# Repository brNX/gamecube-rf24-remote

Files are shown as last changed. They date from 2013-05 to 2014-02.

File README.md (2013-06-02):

# gamecube-rf24-remote

Remote control using an atmega88, nrf24l01+ and a Gamecube gamepad 

gamecube gamepad code adapted from [http://denki.world3.net/retro_v2.html](http://denki.world3.net/retro_v2.html)   
nrf24l01+ code adapted from  Maniacbug's rf24 library for arduino [https://github.com/maniacbug/RF24](https://github.com/maniacbug/RF24)

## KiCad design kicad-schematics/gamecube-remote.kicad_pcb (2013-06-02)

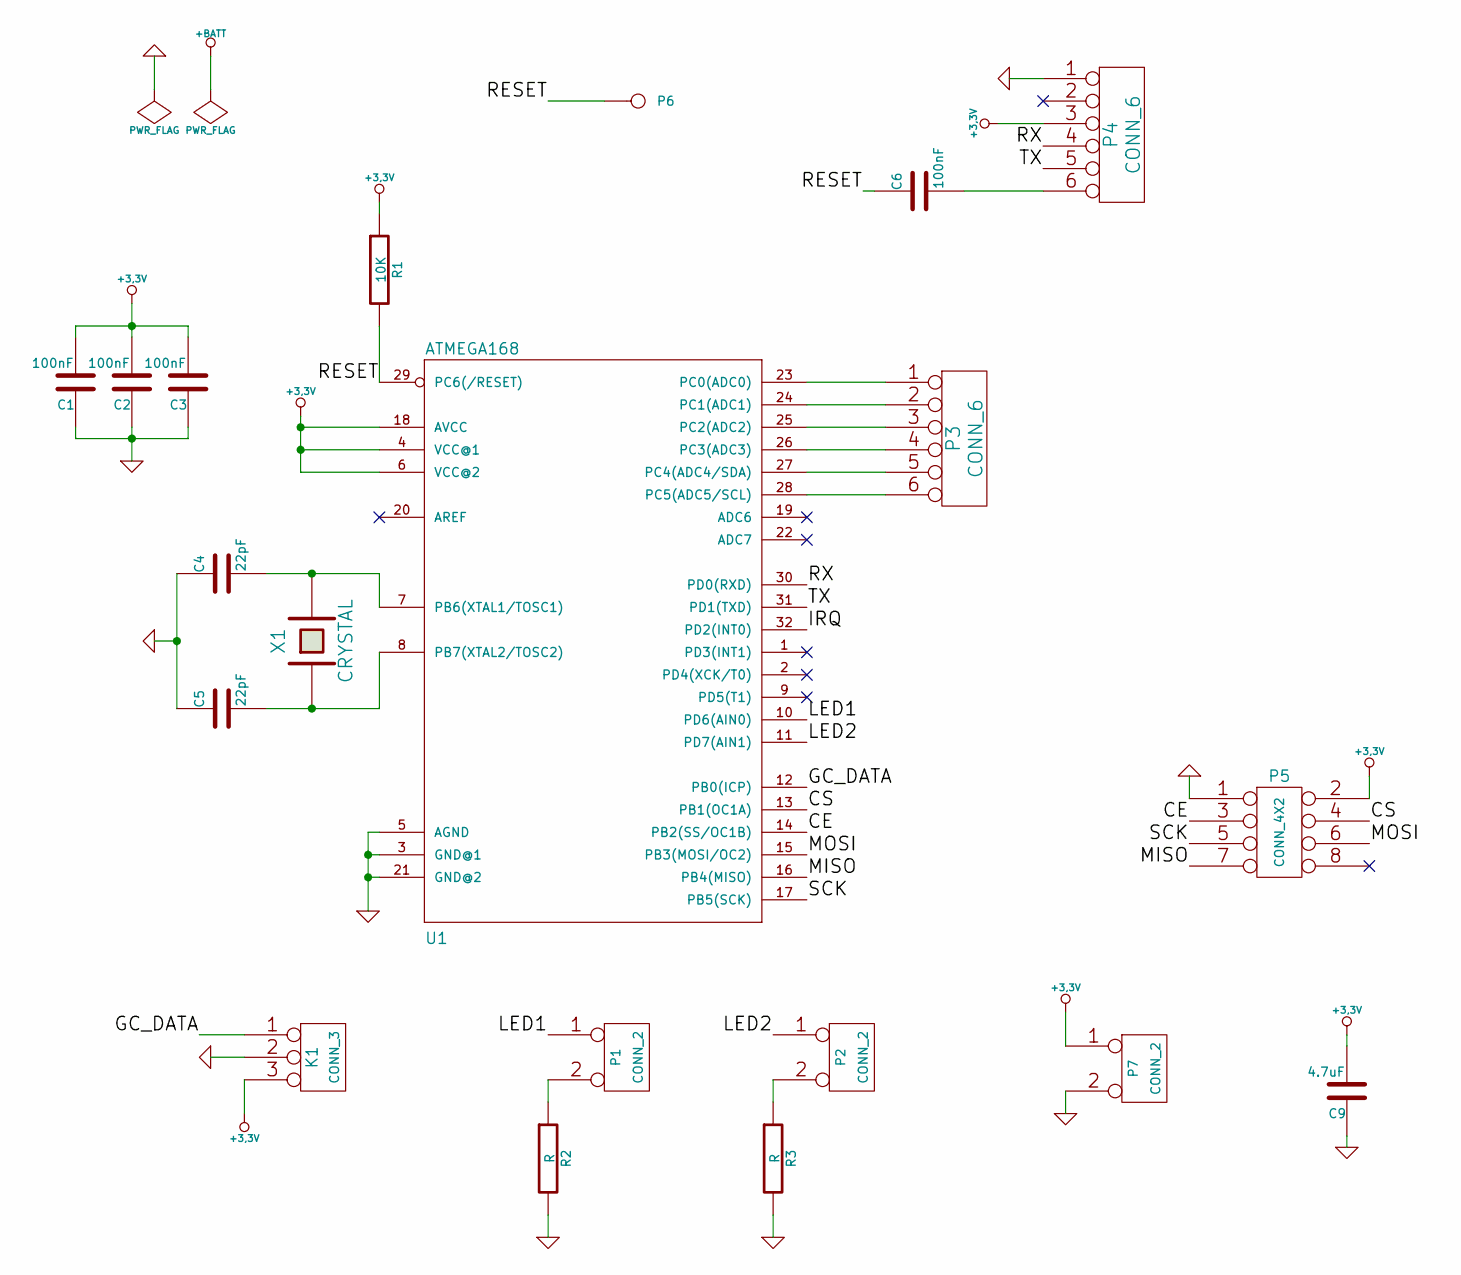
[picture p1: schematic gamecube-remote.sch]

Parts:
C1, C2, C3, C6: 100nF
C4, C5: 22pF
C9: 4.7uF
K1: CONN_3
P1, P2, P7: CONN_2
P3, P4: CONN_6
P5: CONN_4X2
P6: CONN_1
R1: 10K
R2, R3: R
U1: ATMEGA168; SparkFun-TQFP32-08
X1: CRYSTAL

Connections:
+3.3V: C1.2, C2.2, C3.2, C9.2, K1.3, P4.3, P5.2, P7.1, R1.1, U1.4 (VCC@1), U1.6 (VCC@2), U1.18 (AVCC); also elsewhere on the board
/CE: P5.3, U1.14 (PB2(SS/OC1B))
/CS: P5.4, U1.13 (PB1(OC1A))
/GC_DATA: K1.1, U1.12 (PB0(ICP))
/IRQ: U1.32 (PD2(INT0))
/LED1: P1.1, U1.10 (PD6(AIN0))
/LED2: P2.1, U1.11 (PD7(AIN1))
/MISO: P5.7, U1.16 (PB4(MISO))
/MOSI: P5.6, U1.15 (PB3(MOSI/OC2))
/RESET: C6.1, P6.1, R1.2, U1.29 (PC6(/RESET))
/RX: P4.4, U1.30 (PD0(RXD))
/SCK: P5.5, U1.17 (PB5(SCK))
/TX: P4.5, U1.31 (PD1(TXD))
GND: C1.1, C2.1, C3.1, C4.1, C5.1, C9.1, K1.2 (PM), P4.1, P5.1, P7.2 (PM), R2.2, R3.2, U1.3 (GND@1), U1.5 (AGND), U1.21 (GND@2); also elsewhere on the board
unnamed: P3.4, U1.26 (PC3(ADC3))
unnamed: P3.1, U1.23 (PC0(ADC0))
unnamed: P3.2, U1.24 (PC1(ADC1))
unnamed: P3.3, U1.25 (PC2(ADC2))
unnamed: P3.5, U1.27 (PC4(ADC4/SDA))
unnamed: P3.6, U1.28 (PC5(ADC5/SCL))
unnamed: C6.2, P4.6
unnamed: C5.2, U1.8 (PB7(XTAL2/TOSC2)), X1.1
unnamed: C4.2, U1.7 (PB6(XTAL1/TOSC1)), X1.2
unnamed: P2.2 (PM), R3.1
unnamed: P1.2 (PM), R2.1

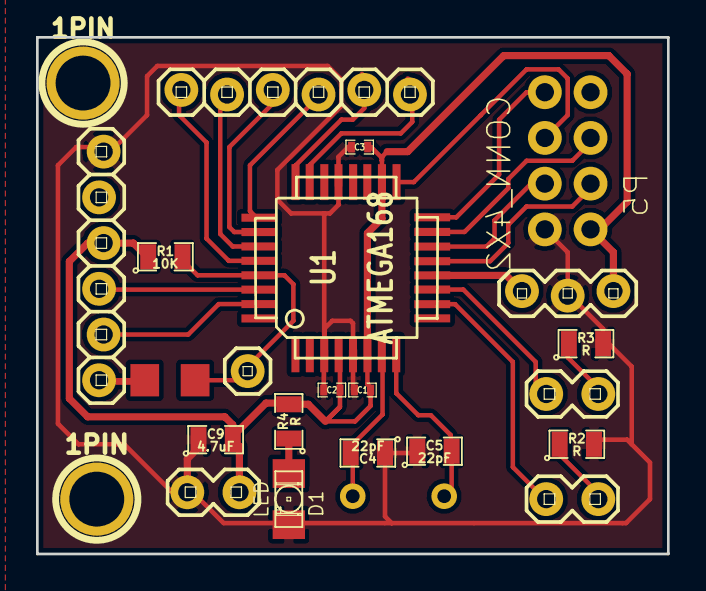
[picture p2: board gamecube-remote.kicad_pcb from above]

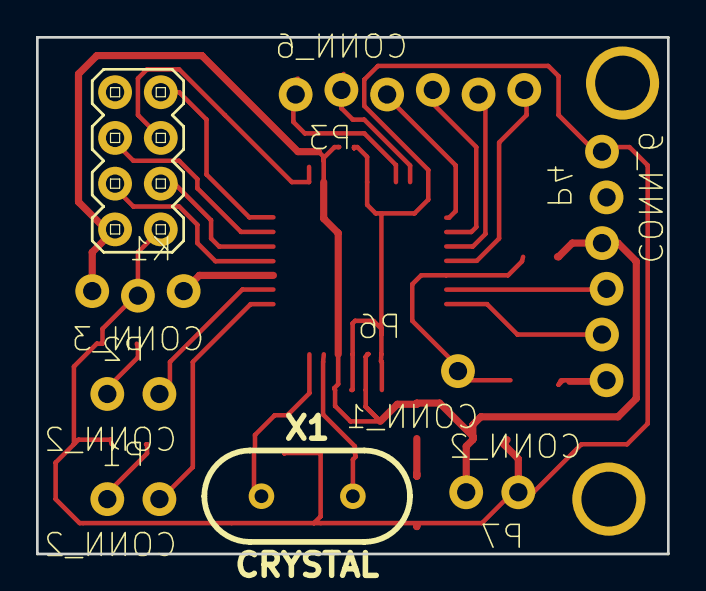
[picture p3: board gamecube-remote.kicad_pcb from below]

Board: 2 copper layers, 35.1 x 28.7 mm, 24 parts (2 on the bottom side), 25 nets.

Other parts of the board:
1PIN, 1PIN#2: P***; 1pin
D1: LED; LED-1206
R4: R; SM0805

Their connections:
+3.3V: R4.2; also elsewhere on the board
GND: D1.2; also elsewhere on the board
unnamed: D1.1, R4.1

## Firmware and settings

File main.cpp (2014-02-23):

/*
 * main.c
 *
 *  Created on: 5 de Mai de 2013
 *      Author: brNX
 */

#include <avr/io.h>
#include <avr/interrupt.h>  /* for sei() */
#include <util/delay.h>     /* for _delay_ms() */
#include <stdio.h>
#include <stdbool.h>
#include <limits.h>
#include <avr/sleep.h>
#include <avr/power.h>
#include <avr/eeprom.h>

extern "C" {
#include "report.h"
#include "n64gc.h"
#include "USART_Int_atmega328.h"
#include "rf24/timer2.h"
}

#include "rf24/RF24.h"

#define LED1 PB6
#define LED2 PB7

#define EEPROM_MAGIC_NUMBER 20

static	report_t reportBuffer;

#define START_PRESSED 	(reportBuffer.b2 & (1<<0))
#define Z_PRESSED 		(reportBuffer.b2 & (1<<1))
#define A_PRESSED 		(reportBuffer.b1 & (1<<0))
#define B_PRESSED 		(reportBuffer.b1 & (1<<1))
#define X_PRESSED 		(reportBuffer.b1 & (1<<3))
#define Y_PRESSED 		(reportBuffer.b1 & (1<<4))
#define L_PRESSED 		(reportBuffer.b1 & (1<<6))
#define R_PRESSED 		(reportBuffer.b1 & (1<<7))


//digital pad
#define UP_PRESSED		(reportBuffer.hat==0)
#define DOWN_PRESSED	(reportBuffer.hat==4)
#define LEFT_PRESSED	(reportBuffer.hat==6)
#define RIGHT_PRESSED	(reportBuffer.hat==2)
#define URIGHT_PRESSED	(reportBuffer.hat==1)
#define DRIGHT_PRESSED	(reportBuffer.hat==3)
#define ULEFT_PRESSED	(reportBuffer.hat==7)
#define DLEFT_PRESSED	(reportBuffer.hat==5)

#define DEADZONE 7


//
// Sleep declarations
//

typedef enum { wdt_16ms = 0, wdt_32ms, wdt_64ms, wdt_128ms, wdt_250ms, wdt_500ms, wdt_1s, wdt_2s, wdt_4s, wdt_8s } wdt_prescalar_e;

void setup_watchdog(uint8_t prescalar);
void do_sleep(void);
void ReadController();
long map(long x, long in_min, long in_max, long out_min, long out_max);
void HardwareInit();
void calibrate();
void convertAxes();
void sendData(bool askforStatus,RF24 & radio);


char maxy=CHAR_MIN,miny=CHAR_MAX,minx=CHAR_MAX,maxx=CHAR_MIN,minrx=CHAR_MAX,maxrx=CHAR_MIN,minry=CHAR_MAX,maxry=CHAR_MIN;
bool calibrated = false;

long map(long x, long in_min, long in_max, long out_min, long out_max) {
	return (x - in_min) * (out_max - out_min) / (in_max - in_min) + out_min;
}


int main (){


	HardwareInit();

	RF24 radio = RF24();
	// Radio pipe addresses for the 2 nodes to communicate.
	const uint64_t pipes[2] = { 0xF0F0F0F0BELL, 0xF0F0F0F0EFLL };

	setup_watchdog(wdt_64ms);

	//
	// Setup and configure rf radio
	//
	radio.begin();

	radio.setChannel(100);

	// optionally, increase the delay between retries & # of retries
	radio.setRetries(15,15);

	// optionally, reduce the payload size.  seems to
	// improve reliability
	radio.setPayloadSize(sizeof(report_t));

	radio.setDataRate(RF24_250KBPS);
	radio.openWritingPipe(pipes[0]);
	radio.openReadingPipe(1,pipes[1]);
	radio.startListening();
	radio.stopListening();

	//unsigned long  pa = 0;
	uint8_t counter = 0;


	//check eeprom
	if (eeprom_read_byte(0)==EEPROM_MAGIC_NUMBER){
		minx=(char)eeprom_read_byte((uint8_t*)1);
		maxx=(char)eeprom_read_byte((uint8_t*)2);
		miny=(char)eeprom_read_byte((uint8_t*)3);
		maxy=(char)eeprom_read_byte((uint8_t*)4);
		minrx=(char)eeprom_read_byte((uint8_t*)5);
		maxrx=(char)eeprom_read_byte((uint8_t*)6);
		minry=(char)eeprom_read_byte((uint8_t*)7);
		maxry=(char)eeprom_read_byte((uint8_t*)8);
		calibrated=true;

#ifdef DEBUG
		print_string("read eeprom magic number");
		char temp[100];
		sprintf(temp,"minx:%d maxx:%d minry:%d maxry:%d \n",minx,maxx,minry,maxry);
		print_string(temp);
		_delay_ms(2000);
#endif

	}


	while(1){

		ReadController();
#ifdef DEBUG
		char temp[100];
		print_string("before convert\n");
		sprintf(temp,"hat:%u x:%d y:%d rx:%d ry:%d b1:%u b2:%u\n",reportBuffer.hat,(int8_t)reportBuffer.x,(int8_t)reportBuffer.y,(int8_t)reportBuffer.rx,(int8_t)reportBuffer.ry,reportBuffer.b1,reportBuffer.b2);
		print_string(temp);
#endif

		convertAxes();

#ifdef DEBUG
		sprintf(temp,"hat:%u x:%d y:%d rx:%d ry:%d b1:%u b2:%u\n",reportBuffer.hat,(int8_t)reportBuffer.x,(int8_t)reportBuffer.y,(int8_t)reportBuffer.rx,(int8_t)reportBuffer.ry,reportBuffer.b1,reportBuffer.b2);
		print_string(temp);
#endif

		//Calibration
		if(A_PRESSED && B_PRESSED && Z_PRESSED && L_PRESSED && R_PRESSED){
			calibrate();
		}

		counter=(counter+1)%20;
		sendData(counter==0,radio);


		do_sleep();
	}
	//never reached
	return 0;
}


//
// Sleep helpers
//

// 0=16ms, 1=32ms,2=64ms,3=125ms,4=250ms,5=500ms
// 6=1 sec,7=2 sec, 8=4 sec, 9= 8sec

void setup_watchdog(uint8_t prescalar)
{
	prescalar = min(9,prescalar);
	uint8_t wdtcsr = prescalar & 7;
	if ( prescalar & 8 )
		wdtcsr |= _BV(WDP3);

	MCUSR &= ~_BV(WDRF);
	WDTCSR = _BV(WDCE) | _BV(WDE);
	WDTCSR = _BV(WDCE) | wdtcsr | _BV(WDIE);
}

ISR(WDT_vect)
{
	;
}

void do_sleep(void)
{
	set_sleep_mode(SLEEP_MODE_PWR_DOWN); // sleep mode is set here
	sleep_enable();

	sleep_mode();                        // System sleeps here

	sleep_disable();                     // System continues execution here when watchdog timed out
}


inline void ReadController(){
	reportBuffer.y = reportBuffer.x = reportBuffer.b1 = reportBuffer.b2 = 0;
	reportBuffer.rx = reportBuffer.ry = 0;
	reportBuffer.hat = -1;

	ReadN64GC(&reportBuffer);
}


void HardwareInit(){

#ifdef DEBUG
	USART_Init(16); //(16)115200 8N1 (16MHz crystal)
#endif

	timer2_setup();

	DDRD	= (1<<LED1) | (1<<LED2) ; //status led1 & 2 output
	PORTD	= 0;

	DDRB	&= ~(1<<PB0);
	PORTB	|=  (1<<PB0);	// PB0 input with pull-up

	sei();
}

void calibrate()
{

#ifdef DEBUG
	print_string("calibration entered\n");
#endif
	PORTD |= (1 << LED2);
	PORTD |= (1 << LED1);

	maxx=0;
	minx=255;
	maxy=0;
	miny=255;
	maxrx=0;
	minrx=255;
	maxry=0;
	minry=255;

	while (1)
	{
		ReadController();
		if (START_PRESSED)
			break;

		if (reportBuffer.x > maxx)
		{
			maxx = reportBuffer.x;
		}
		if (reportBuffer.rx > maxrx)
		{
			maxrx =  reportBuffer.rx;
		}
		if ( reportBuffer.y > maxy)
		{
			maxy =  reportBuffer.y;
		}
		if ( reportBuffer.ry > maxry)
		{
			maxry =  reportBuffer.ry;
		}
		if ( reportBuffer.x < minx)
		{
			minx =  reportBuffer.x;
		}
		if ( reportBuffer.rx < minrx)
		{
			minrx =  reportBuffer.rx;
		}
		if ( reportBuffer.y < miny)
		{
			miny =  reportBuffer.y;
		}
		if ( reportBuffer.ry < minry)
		{
			minry =  reportBuffer.ry;
		}

		PORTD ^= (1 << LED2);
		_delay_ms(64);
	}
	calibrated = true;

	if (eeprom_read_byte(0)!=EEPROM_MAGIC_NUMBER){
		eeprom_write_byte(0,EEPROM_MAGIC_NUMBER);
	}
	eeprom_write_byte((uint8_t*)1,(uint8_t)minx);
	eeprom_write_byte((uint8_t*)2,(uint8_t)maxx);
	eeprom_write_byte((uint8_t*)3,(uint8_t)miny);
	eeprom_write_byte((uint8_t*)4,(uint8_t)maxy);
	eeprom_write_byte((uint8_t*)5,(uint8_t)minrx);
	eeprom_write_byte((uint8_t*)6,(uint8_t)maxrx);
	eeprom_write_byte((uint8_t*)7,(uint8_t)minry);
	eeprom_write_byte((uint8_t*)8,(uint8_t)maxry);
	calibrated=true;

#ifdef DEBUG
		char temp[100];
		sprintf(temp,"min:%d %d max:%d %d minr;%d %d maxr: %d %d\n",minx,miny,maxx,maxy,minrx,minry,maxrx,maxry);
		print_string(temp);
#endif



	PORTD &= ~(1 << LED2);
	PORTD &= ~(1 << LED1);
}

inline char clamp(char x, char min, char max)
{
    return x < min ? min : (x > max ? max : x);
}


inline void convertAxes()
{
	//DEADZONE check
	if (reportBuffer.x >= -DEADZONE && reportBuffer.x <= DEADZONE){
		reportBuffer.x = 0;
	}
	if (reportBuffer.y >= -DEADZONE && reportBuffer.y <= DEADZONE){
		reportBuffer.y = 0;
	}
	if (reportBuffer.rx >= -DEADZONE && reportBuffer.rx <= DEADZONE){
		reportBuffer.rx = 0;
	}
	if (reportBuffer.ry >= -DEADZONE && reportBuffer.ry <= DEADZONE){
		reportBuffer.ry = 0;
	}


	if (calibrated){

		if (reportBuffer.x !=0){
			//clamp variable
			reportBuffer.x = clamp(reportBuffer.x,minx,maxx);
			//convert to range
			if (reportBuffer.x > 0){
				reportBuffer.x = (char) (map(reportBuffer.x, DEADZONE, maxx, 1, 127));
			}else{
				reportBuffer.x = (char) (map(reportBuffer.x, minx, -DEADZONE, -127, -1));
			}
		}

		if (reportBuffer.y != 0){
			//clamp variable
			reportBuffer.y= clamp(reportBuffer.y,miny,maxy);

			//convert to range
			if (reportBuffer.y > 0){
				reportBuffer.y = (char) (map(reportBuffer.y, DEADZONE, maxy, 1, 127));
			}else{
				reportBuffer.y = (char) (map(reportBuffer.y, miny, -DEADZONE, -127, -1));
			}
		}

		if (reportBuffer.rx != 0){
			//clamp variable
			reportBuffer.rx = clamp(reportBuffer.rx,minrx,maxrx);

			//convert to range
			if (reportBuffer.rx > 0){
				reportBuffer.rx = (char) (map(reportBuffer.rx, DEADZONE, maxrx, 1, 127));
			}else{
				reportBuffer.rx = (char) (map(reportBuffer.rx, minrx, -DEADZONE, -127, -1));
			}
		}

		if (reportBuffer.ry != 0){
			//clamp variable
			reportBuffer.ry = clamp(reportBuffer.ry,minry,maxry);

			//convert to range
			if (reportBuffer.ry > 0){
				reportBuffer.ry = (char) (map(reportBuffer.ry, DEADZONE, maxry, 1, 127));
			}else{
				reportBuffer.ry = (char) (map(reportBuffer.ry, minry, -DEADZONE, -127, -1));
			}
		}

	}
}

inline void sendData(bool askforStatus,RF24 & radio){
	reportBuffer.reportid=askforStatus?1:0;
	bool ok = radio.write( &reportBuffer, sizeof(report_t) );

	if (ok){
		//status led off
		PORTD	&= ~(1<<LED1);
	}
	else{
		//status led on
		PORTD	|= (1<<LED1);
#ifdef DEBUG
		print_string("pa error\n");
#endif
		radio.startListening();
		radio.stopListening();
		return;
	}

	radio.startListening();

	if (askforStatus){

		// Wait here until we get a response, or timeout (250ms)
		bool timeout = false;
		timer2_start();
		while ( ! radio.available() && ! timeout ){
			if (timer2_gettick() > 200 )
				timeout = true;
		}

		// Describe the results
		if ( timeout )
		{
			//status led on
			PORTD	|= (1<<LED1);
#ifdef DEBUG
			print_string("Failed, response timed out.\n\r");
#endif
		}
		else
		{
			uint8_t response;
			radio.read( &response, sizeof(uint8_t) );
			//status led off
			PORTD	&= ~(1<<LED1);

			if (response){
				//battery led on
#ifdef DEBUG
				print_string("led on\n");
#endif
				PORTD	|= (1<<LED2);
			}else{
				//battery led off
				PORTD	&= ~(1<<LED2);
#ifdef DEBUG
				print_string("led off\n");
#endif
			}
		}

		timer2_stop();
	}

	radio.stopListening();
}

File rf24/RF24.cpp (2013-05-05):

/*
 Copyright (C) 2011 J. Coliz <maniacbug@ymail.com>

 This program is free software; you can redistribute it and/or
 modify it under the terms of the GNU General Public License
 version 2 as published by the Free Software Foundation.
 */

#include "nRF24L01.h"
#include "RF24_config.h"
#include "RF24.h"
extern "C"{
#include "spi.h"
#include "timer2.h"
#ifdef PRINT_STATUS
#include "../USART_Int_atmega328.h"
#endif
}
#define LOW 0
#define HIGH 1

/****************************************************************************/

void RF24::csn(int mode)
{
	// Minimum ideal SPI bus speed is 2x data rate
	// If we assume 2Mbs data rate and 16Mhz clock, a
	// divider of 4 is the minimum we want.
	// CLK:BUS 8Mhz:2Mhz, 16Mhz:4Mhz, or 20Mhz:5Mhz
	if (mode)
		spi_cs_high();
	else
		spi_cs_low();
}

/****************************************************************************/

void RF24::ce(int level)
{
	if(level)
		spi_ce_high();
	else
		spi_ce_low();
}

/****************************************************************************/

uint8_t RF24::read_register(uint8_t reg, uint8_t* buf, uint8_t len)
{
	uint8_t status;

	csn(LOW);
	status = spi_transferByte( R_REGISTER | ( REGISTER_MASK & reg ) );
	while ( len-- )
		*buf++ = spi_transferByte(0xff);

	csn(HIGH);

	return status;
}

/****************************************************************************/

uint8_t RF24::read_register(uint8_t reg)
{
	csn(LOW);
	spi_transferByte( R_REGISTER | ( REGISTER_MASK & reg ) );
	uint8_t result = spi_transferByte(0xff);

	csn(HIGH);
	return result;
}

/****************************************************************************/

uint8_t RF24::write_register(uint8_t reg, const uint8_t* buf, uint8_t len)
{
	uint8_t status;

	csn(LOW);
	status = spi_transferByte( W_REGISTER | ( REGISTER_MASK & reg ) );
	while ( len-- )
		spi_transferByte(*buf++);

	csn(HIGH);

	return status;
}

/****************************************************************************/

uint8_t RF24::write_register(uint8_t reg, uint8_t value)
{
	uint8_t status;

	IF_SERIAL_DEBUG(sprintf_P(PSTR("write_register(%02x,%02x)\r\n"),reg,value));

	csn(LOW);
	status = spi_transferByte( W_REGISTER | ( REGISTER_MASK & reg ) );
	spi_transferByte(value);
	csn(HIGH);

	return status;
}

/****************************************************************************/

uint8_t RF24::write_payload(const void* buf, uint8_t len)
{
	uint8_t status;

	const uint8_t* current = reinterpret_cast<const uint8_t*>(buf);

	uint8_t data_len = min(len,payload_size);
	uint8_t blank_len = dynamic_payloads_enabled ? 0 : payload_size - data_len;

	//printf("[Writing %u bytes %u blanks]",data_len,blank_len);

	csn(LOW);
	status = spi_transferByte( W_TX_PAYLOAD );
	while ( data_len-- )
		spi_transferByte(*current++);
	while ( blank_len-- )
		spi_transferByte(0);
	csn(HIGH);

	return status;
}

/****************************************************************************/

uint8_t RF24::read_payload(void* buf, uint8_t len)
{
	uint8_t status;
	uint8_t* current = reinterpret_cast<uint8_t*>(buf);

	uint8_t data_len = min(len,payload_size);
	uint8_t blank_len = dynamic_payloads_enabled ? 0 : payload_size - data_len;

	//printf("[Reading %u bytes %u blanks]",data_len,blank_len);

	csn(LOW);
	status = spi_transferByte( R_RX_PAYLOAD );
	while ( data_len-- )
		*current++ = spi_transferByte(0xff);
	while ( blank_len-- )
		spi_transferByte(0xff);
	csn(HIGH);

	return status;
}

/****************************************************************************/

uint8_t RF24::flush_rx(void)
{
	uint8_t status;

	csn(LOW);
	status = spi_transferByte( FLUSH_RX );
	csn(HIGH);

	return status;
}

/****************************************************************************/

uint8_t RF24::flush_tx(void)
{
	uint8_t status;

	csn(LOW);
	status = spi_transferByte( FLUSH_TX );
	csn(HIGH);

	return status;
}

/****************************************************************************/

uint8_t RF24::get_status(void)
{
	uint8_t status;

	csn(LOW);
	status = spi_transferByte( NOP );
	csn(HIGH);

	return status;
}

/****************************************************************************/

void RF24::print_status(uint8_t status)
{
#ifdef PRINT_STATUS
	char temp[50];
	sprintf_P(temp,PSTR("STATUS\t\t = 0x%02x RX_DR=%x TX_DS=%x MAX_RT=%x RX_P_NO=%x TX_FULL=%x\r\n"),
			status,
			(status & _BV(RX_DR))?1:0,
					(status & _BV(TX_DS))?1:0,
							(status & _BV(MAX_RT))?1:0,
									((status >> RX_P_NO) & 0b111),
									(status & _BV(TX_FULL))?1:0
	);
	print_string(temp);
#endif
}

/****************************************************************************/

void RF24::print_observe_tx(uint8_t value)
{
#ifdef PRINT_STATUS
	char temp[50];
	sprintf_P(temp,PSTR("OBSERVE_TX=%02x: POLS_CNT=%x ARC_CNT=%x\r\n"),
			value,
			(value >> PLOS_CNT) & 0b1111,
			(value >> ARC_CNT) & 0b1111
	);
	print_string(temp);
#endif
}

/****************************************************************************/

void RF24::print_byte_register(const char* name, uint8_t reg, uint8_t qty)
{
#ifdef PRINT_STATUS
	char temp[50];
	char extra_tab = strlen_P(name) < 8 ? '\t' : 0;
	sprintf_P(temp,PSTR(PRIPSTR"\t%c ="),name,extra_tab);
	print_string(temp);
	while (qty--){
		sprintf_P(temp,PSTR(" 0x%02x"),read_register(reg++));
		print_string(temp);
	}
	sprintf_P(temp,PSTR("\r\n"));
	print_string(temp);
#endif
}

/****************************************************************************/

void RF24::print_address_register(const char* name, uint8_t reg, uint8_t qty)
{
#ifdef PRINT_STATUS
	char temp[50];
	char extra_tab = strlen_P(name) < 8 ? '\t' : 0;
	sprintf_P(temp,PSTR(PRIPSTR"\t%c ="),name,extra_tab);
	print_string(temp);

	while (qty--)
	{
		uint8_t buffer[5];
		read_register(reg++,buffer,sizeof buffer);

		sprintf_P(temp,PSTR(" 0x"));
		print_string(temp);
		uint8_t* bufptr = buffer + sizeof buffer;
		while( --bufptr >= buffer ){
			sprintf_P(temp,PSTR("%02x"),*bufptr);
			print_string(temp);
		}
	}

	sprintf_P(temp,PSTR("\r\n"));
	print_string(temp);
#endif
}

/****************************************************************************/

RF24::RF24():
				  wide_band(true), p_variant(false),
				  payload_size(32), ack_payload_available(false), dynamic_payloads_enabled(false),
				  pipe0_reading_address(0)
{
}

/****************************************************************************/

void RF24::setChannel(uint8_t channel)
{
	// TODO: This method could take advantage of the 'wide_band' calculation
	// done in setChannel() to require certain channel spacing.

	const uint8_t max_channel = 127;
	write_register(RF_CH,min(channel,max_channel));
}

/****************************************************************************/

void RF24::setPayloadSize(uint8_t size)
{
	const uint8_t max_payload_size = 32;
	payload_size = min(size,max_payload_size);
}

/****************************************************************************/

uint8_t RF24::getPayloadSize(void)
{
	return payload_size;
}
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

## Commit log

2013-05-05 timer2 for timeout, spi pins configuration
2013-05-05 spi working , rf24 working
2013-06-02 calibration , everything tested
2013-06-07 clamp values to min/max
2013-06-07 clamp function
2013-06-09 write and read calibration from eeprom
2014-02-23 calibration variables and map from deadzone instead of 1
